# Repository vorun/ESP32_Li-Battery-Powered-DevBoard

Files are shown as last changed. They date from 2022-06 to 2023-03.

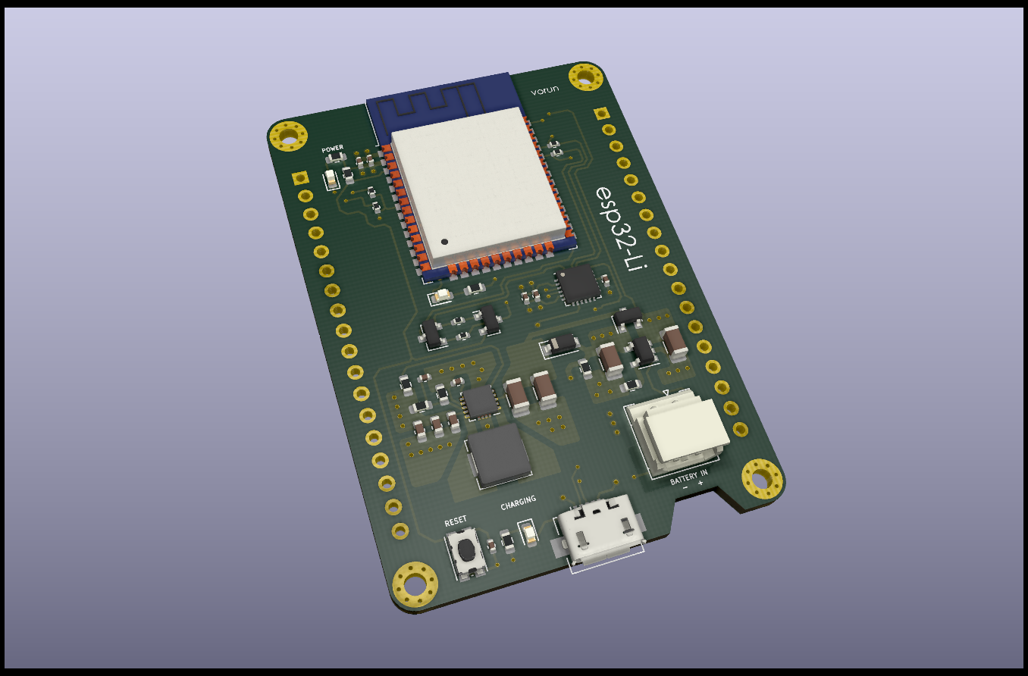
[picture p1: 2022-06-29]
PCB 3D View Top Layer.png

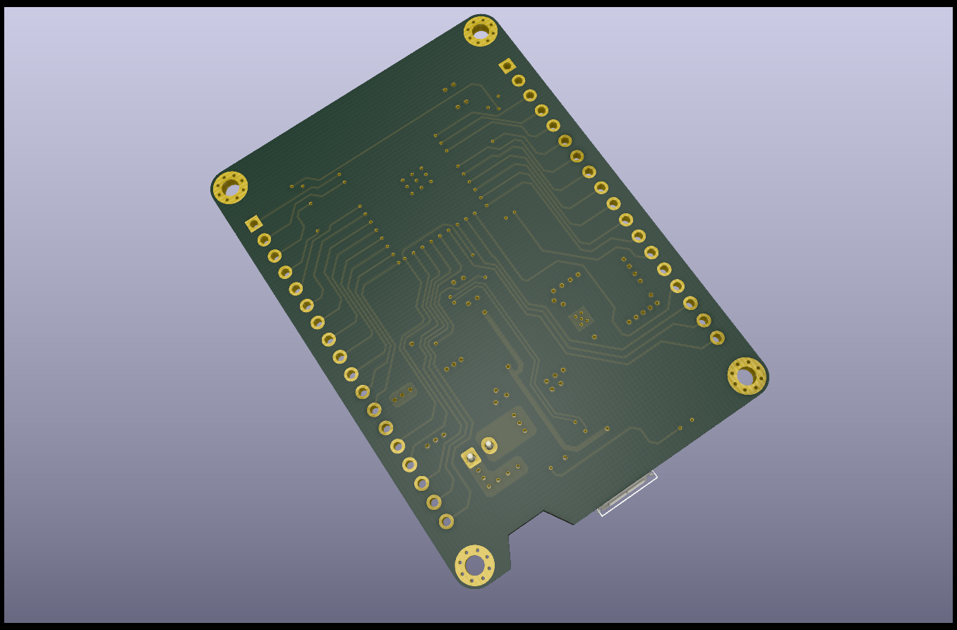
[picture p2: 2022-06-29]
PCB 3D View Bottom Layer.png

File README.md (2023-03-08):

# ESP32_Li-Battery-Powered-DevBoard

Esp32 development board that can be powered by 1S(3.7V) li-po battery with built in charger circuit to charge the battery from micro usb port.

- Green led at the left bottom of the board lights up when the battery is being charged. Board can be powered from micro usb port without the battery.

- Battery charge level can be monitored from GPIO35 pin.

PCB 3D View Bottom Layer
PCB 3D View Top Layer

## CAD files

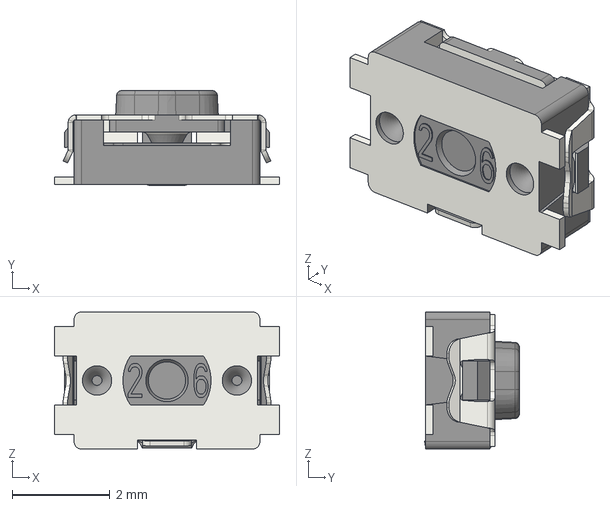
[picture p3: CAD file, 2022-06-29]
STEP Files/Tact.step
4.60 x 1.94 x 2.80 mm

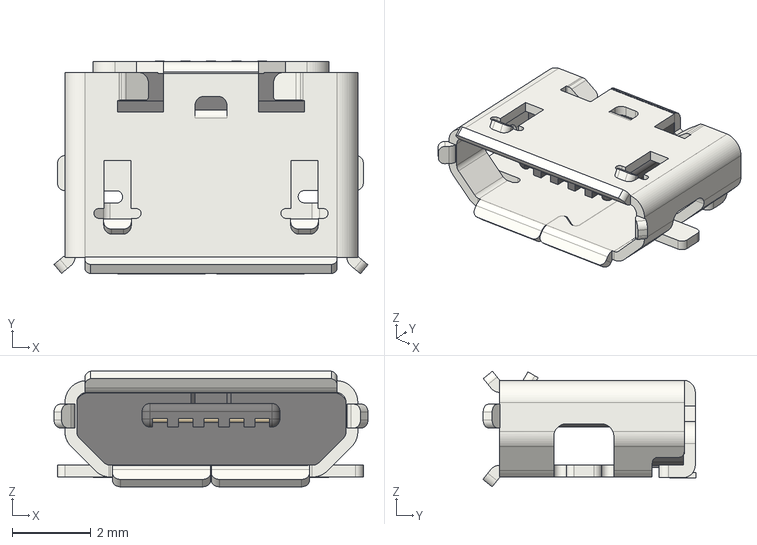
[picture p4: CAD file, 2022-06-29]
STEP Files/USB_Micro-B_Molex_47346-0001.step
7.98 x 5.42 x 2.94 mm

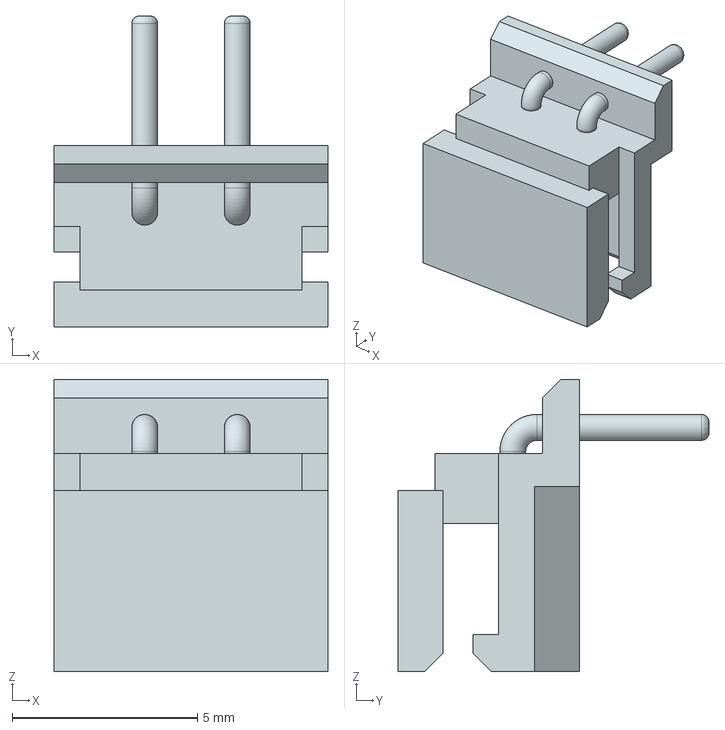
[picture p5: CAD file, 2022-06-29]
STEP Files/022057025.stp
7.40 x 8.40 x 7.90 mm

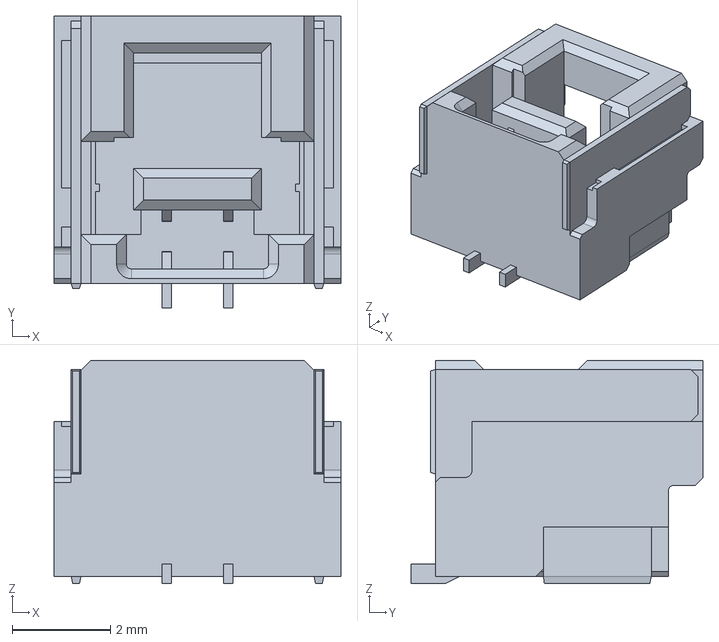
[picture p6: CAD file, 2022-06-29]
STEP Files/5023820270.stp
5.85 x 5.94 x 4.55 mm

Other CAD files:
STEP Files/KMR211GLFS.stp

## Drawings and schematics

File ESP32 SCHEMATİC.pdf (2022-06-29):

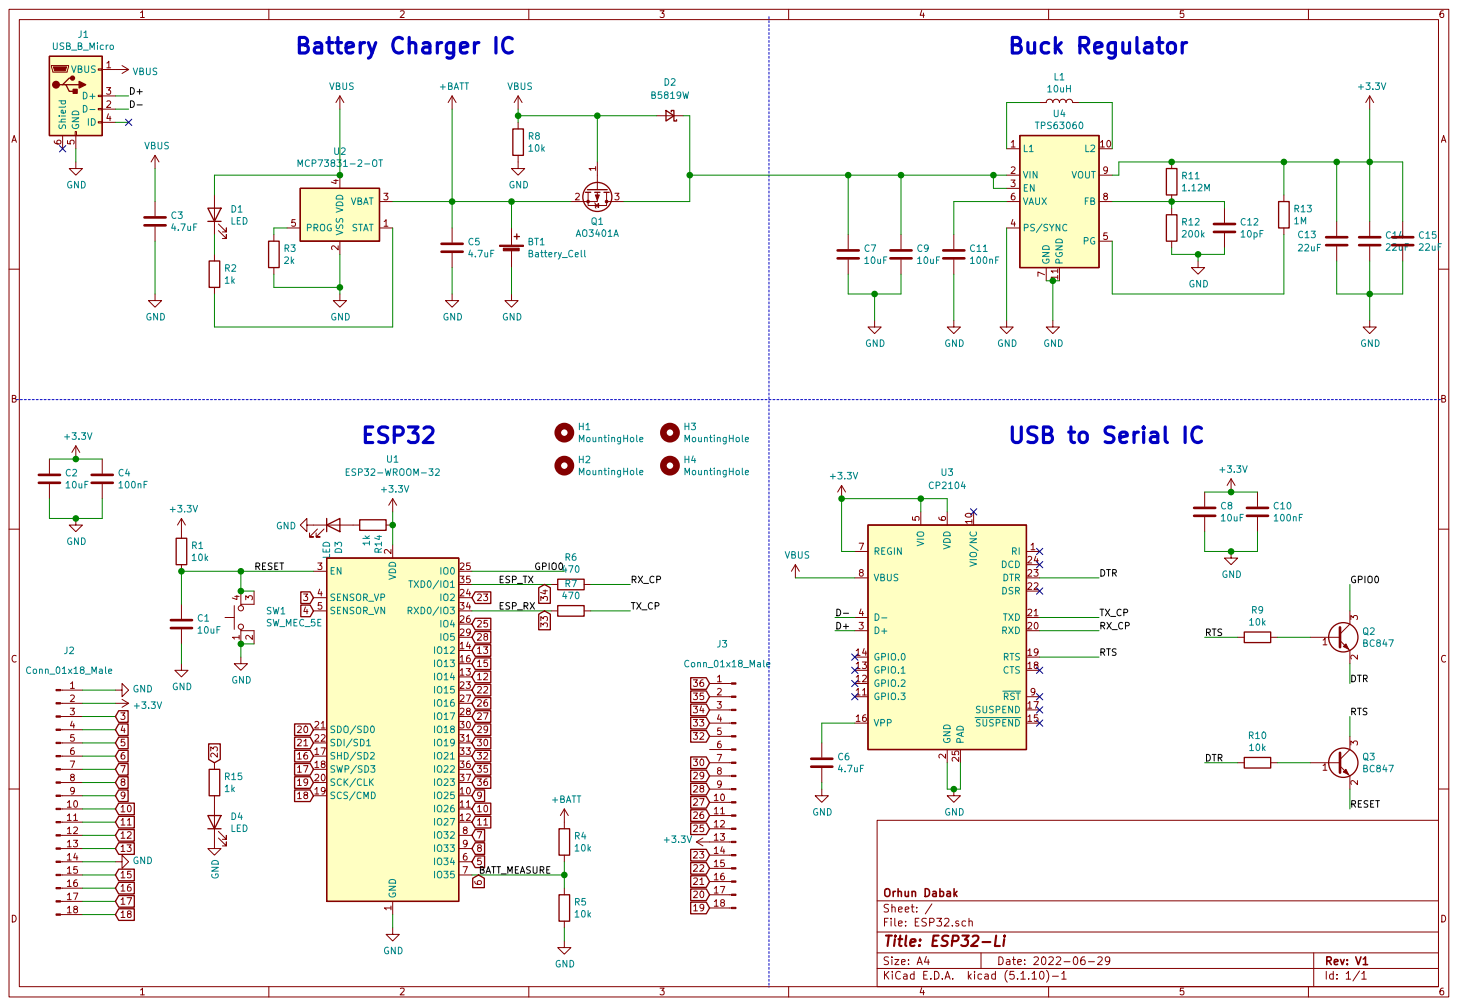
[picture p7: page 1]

2 RXD 20 TXD 21 DSR 22 DTR 23 DCD 24 PAD 25 D+ 3 D- 4 VIO

2 SCK/CLK 20 SDO/SD0 21 SDI/SD1 22

Id: 1/1 Title: ESP32-Li File: ESP32.sch Sheet: / Orhun Dabak

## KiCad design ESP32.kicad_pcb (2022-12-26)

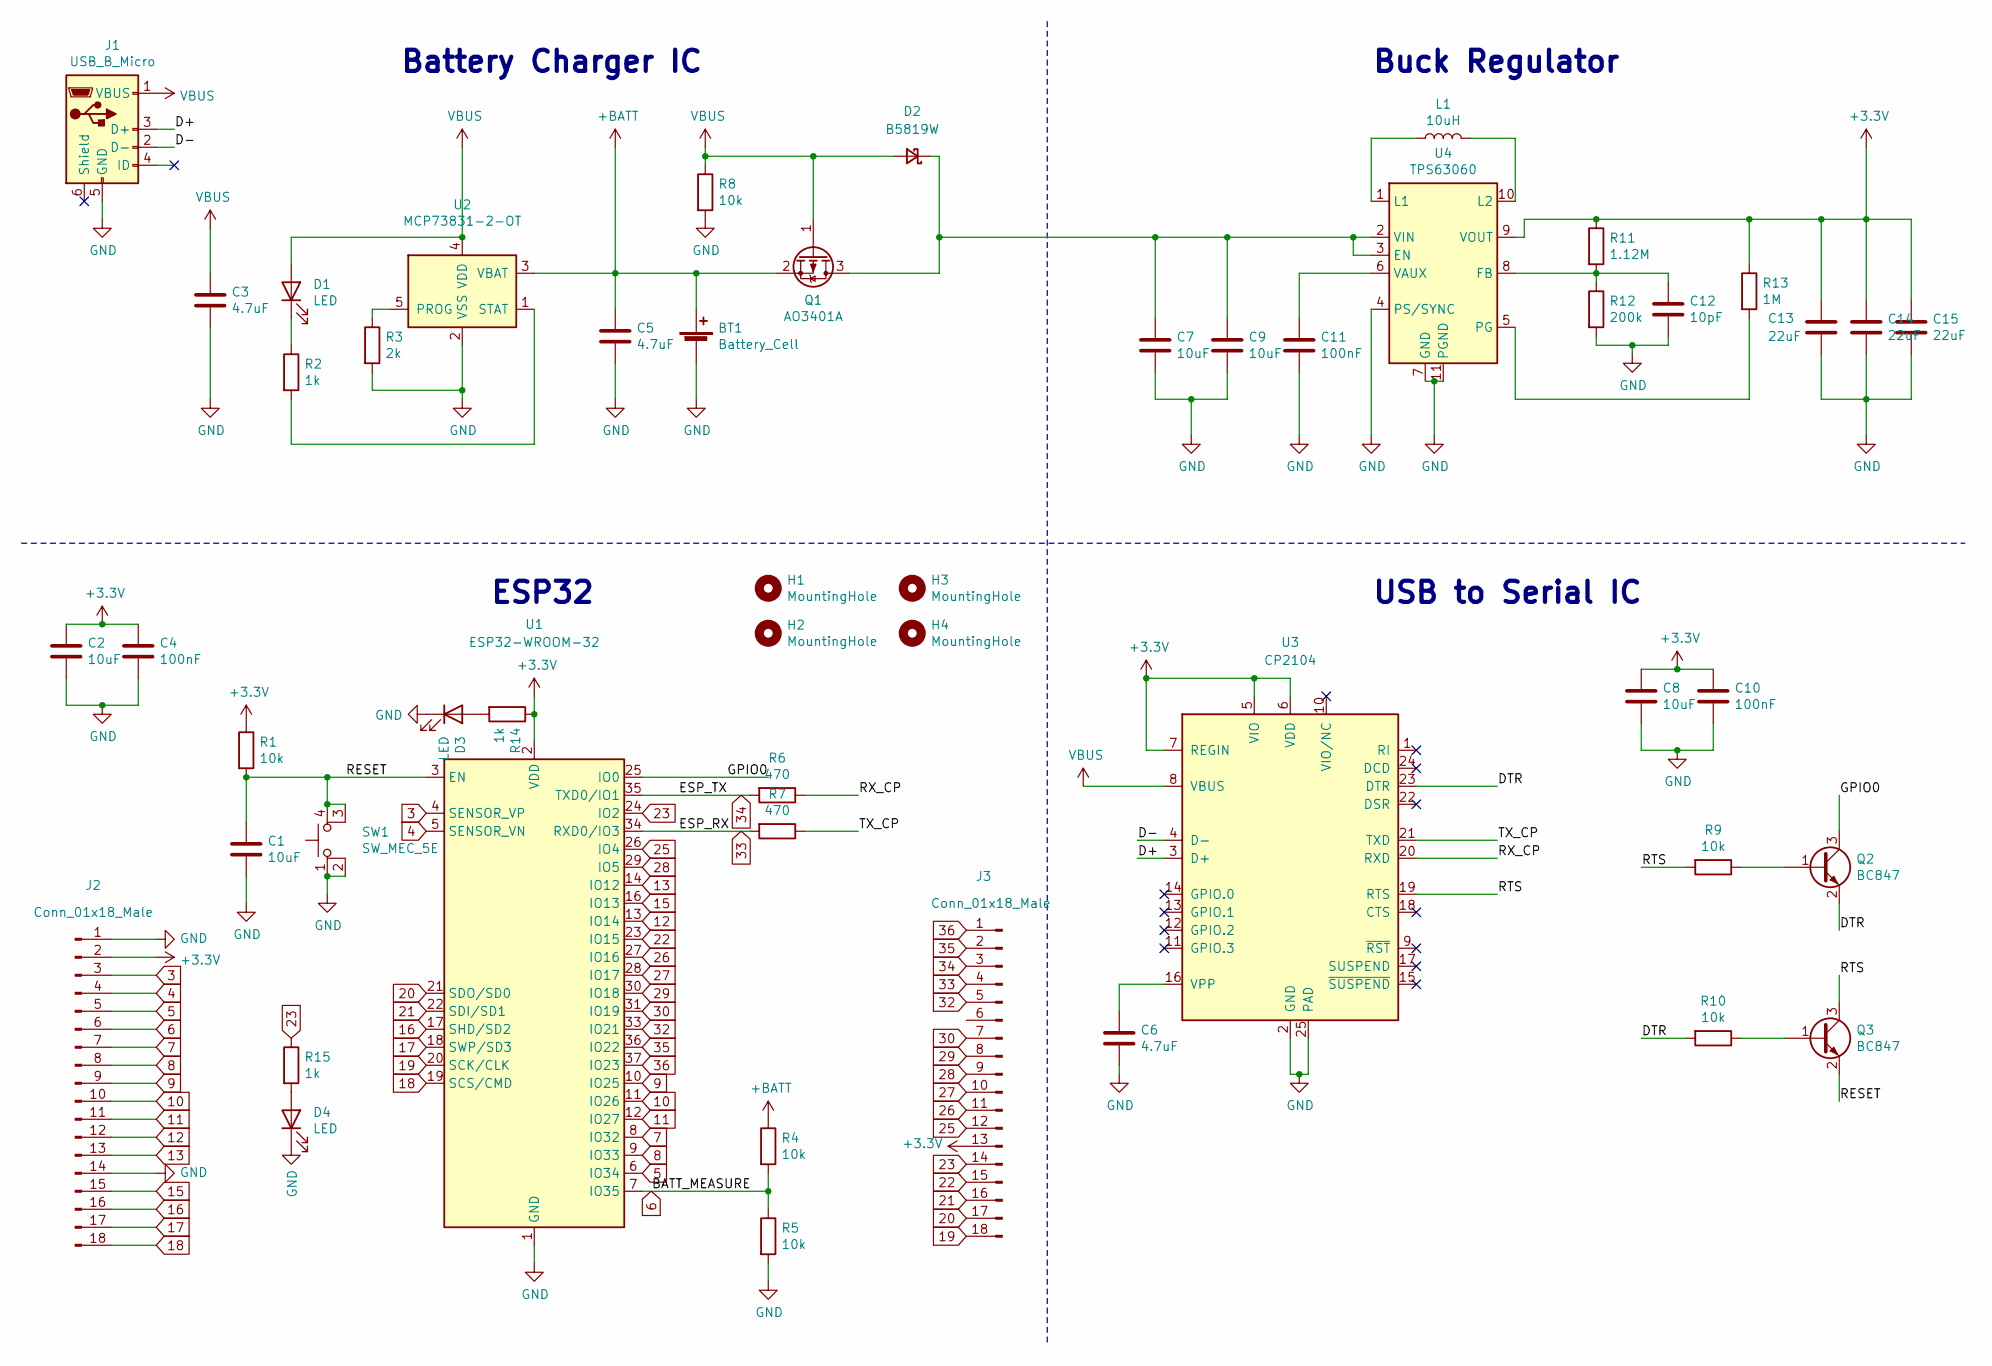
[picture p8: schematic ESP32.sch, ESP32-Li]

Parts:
BT1: Battery_Cell; JST_EH_S2B-EH_1x02_P2.50mm_Horizontal
C1, C2, C8: 10uF; C_0402_1005Metric
C3, C5: 4.7uF; C_1206_3216Metric
C4, C10, C11: 100nF; C_0402_1005Metric
C6: 4.7uF; C_0402_1005Metric
C7, C9: 10uF; C_1206_3216Metric
C12: 10pF; C_0402_1005Metric
C13, C14, C15: 22uF; C_0603_1608Metric
D1, D3, D4: LED; LED_0603_1608Metric
D2: B5819W; D_SOD-123
H1, H2, H3, H4: MountingHole; MountingHole_2.2mm_M2_Pad_Via
J1: USB_B_Micro; USB_Micro-B_Amphenol_10104110_Horizontal
J2, J3: Conn_01x18_Male; PinHeader_1x18_P2.54mm_Vertical
L1: 10uH; L_Sunlord_MWSA0518_5.4x5.2mm
Q1: AO3401A; SOT-23
Q2, Q3: BC847; SOT-23
R1, R8: 10k; R_0603_1608Metric
R2, R14, R15: 1k; R_0603_1608Metric
R3: 2k; R_0603_1608Metric
R4, R5, R9, R10: 10k; R_0402_1005Metric
R6, R7: 470; R_0402_1005Metric
R11: 1.12M; R_0603_1608Metric
R12: 200k; R_0603_1608Metric
R13: 1M; R_0603_1608Metric
SW1: SW_MEC_5E; SW_Push_1P1T_NO_CK_KMR2
U1: ESP32-WROOM-32
U2: MCP73831-2-OT; SOT-23-5
U3: CP2104; QFN-24-1EP_4x4mm_P0.5mm_EP2.6x2.6mm
U4: TPS63060; Texas_S-PWSON-N10_ThermalVias

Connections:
3: J2.3, U1.4 (SENSOR_VP)
4: J2.4, U1.5 (SENSOR_VN)
5: J2.5, U1.6 (IO34)
6: J2.6, R4.2, R5.1, U1.7 (IO35)
7: J2.7, U1.8 (IO32)
8: J2.8, U1.9 (IO33)
9: J2.9, U1.10 (IO25)
10: J2.10, U1.11 (IO26)
11: J2.11, U1.12 (IO27)
12: J2.12, U1.13 (IO14)
13: J2.13, U1.14 (IO12)
15: J2.15, U1.16 (IO13)
16: J2.16, U1.17 (SHD/SD2)
17: J2.17, U1.18 (SWP/SD3)
18: J2.18, U1.19 (SCS/CMD)
19: J3.18, U1.20 (SCK/CLK)
20: J3.17, U1.21 (SDO/SD0)
21: J3.16, U1.22 (SDI/SD1)
22: J3.15, U1.23 (IO15)
23: J3.14, R15.1, U1.24 (IO2)
25: J3.12, U1.26 (IO4)
26: J3.11, U1.27 (IO16)
27: J3.10, U1.28 (IO17)
28: J3.9, U1.29 (IO5)
29: J3.8, U1.30 (IO18)
30: J3.7, U1.31 (IO19)
32: J3.5, U1.33 (IO21)
33: J3.4, R7.2, U1.34 (RXD0/IO3)
34: J3.3, R6.2, U1.35 (TXD0/IO1)
35: J3.2, U1.36 (IO22)
36: J3.1, U1.37 (IO23)
+3V3: C2.1, C4.1, C8.1, C10.1, C13.1, C14.1, C15.1, J2.2, J3.13, R1.1, R11.1, R13.1, R14.1, U1.2 (VDD), U3.5 (VIO), U3.6 (VDD), U3.7 (REGIN), U4.9 (VOUT)
+BATT: BT1.1 (+), C5.1, Q1.2 (S), R4.1, U2.3 (VBAT)
/D+: J1.3 (D+), U3.3 (D+)
/D-: J1.2 (D-), U3.4 (D-)
/DTR: Q2.2 (E), R10.2, U3.23 (DTR)
/GPIO0: Q2.3 (C), U1.25 (IO0)
/RESET: C1.1, Q3.2 (E), R1.2, SW1.3 (K), SW1.4 (A), U1.3 (EN)
/RTS: Q3.3 (C), R9.2, U3.19 (RTS)
/RX_CP: R6.1, U3.20 (RXD)
/TX_CP: R7.1, U3.21 (TXD)
GND: BT1.2 (-), C1.2, C2.2, C3.2, C4.2, C5.2, C6.2, C7.2, C8.2, C9.2, C10.2, C11.2, C12.2, C13.2, C14.2, C15.2, D3.1 (K), D4.1 (K), J1.5 (GND), J2.1, J2.14, R3.2, R5.2, R8.2, R12.2, SW1.1, SW1.2, U1.1 (GND), U1.15 (GND), U1.38 (GND), U1.39 (GND), U2.2 (VSS), U3.2 (GND), U3.25 (PAD), U4.4 (PS/SYNC), U4.7 (GND), U4.11 (PGND)
unnamed: C6.1, U3.16 (VPP)
unnamed: C7.1, C9.1, D2.1 (K), Q1.3 (D), U4.2 (VIN), U4.3 (EN)
unnamed: C11.1, U4.6 (VAUX)
unnamed: C12.1, R11.2, R12.1, U4.8 (FB)
unnamed: D1.1 (K), R2.1
unnamed: D3.2 (A), R14.2
unnamed: D4.2 (A), R15.2
unnamed: L1.1, U4.1 (L1)
unnamed: L1.2, U4.10 (L2)
unnamed: Q2.1 (B), R9.1
unnamed: Q3.1 (B), R10.1
unnamed: R2.2, U2.1 (STAT)
unnamed: R3.1, U2.5 (PROG)
unnamed: R13.2, U4.5 (PG)
VBUS: C3.1, D1.2 (A), D2.2 (A), J1.1 (VBUS), Q1.1 (G), R8.1, U2.4 (VDD), U3.8 (VBUS)

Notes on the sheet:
USB to Serial IC
ESP32
Battery Charger IC
Buck Regulator

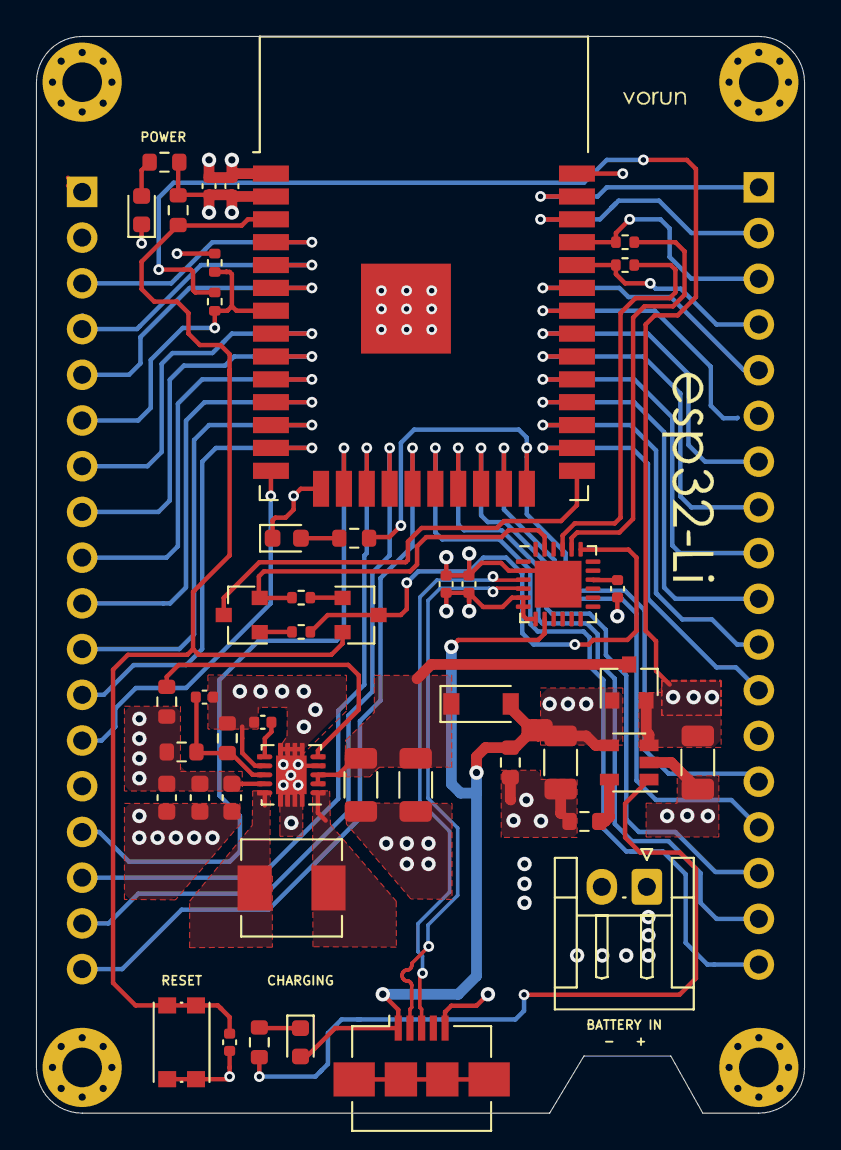
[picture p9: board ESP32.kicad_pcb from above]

Board: 4 copper layers, 42.7 x 59.8 mm, 51 parts (0 on the bottom side), 57 nets.

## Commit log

2022-06-29 Create ESP32 Schematic.pdf
2022-06-29 Schematic added
